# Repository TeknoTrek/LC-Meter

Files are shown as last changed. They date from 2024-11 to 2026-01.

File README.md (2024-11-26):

# DIY LC Meter Project

This project demonstrates how to build a DIY LC Meter capable of measuring inductance (L) and capacitance (C) values using an Arduino Nano, an LM311 comparator, and a 16x2 LCD display. The LC Meter is designed to be simple, affordable, and effective for electronics enthusiasts and DIY hobbyists. It is suitable for learning about measurement principles while also being a practical tool.

## Project Highlights:

### 1 - Circuit Schematic
A detailed circuit diagram explains the working principle and interconnection of components such as the LM311 comparator, relay, calibration buttons, and measurement probes. The schematic provides a foundation for assembling the hardware.

### 2 - PCB Design
A professionally designed single-layer PCB created with KiCad ensures clean routing and minimizes interference. It includes detailed silkscreen labels for easy assembly and debugging.

### 3 - 3D Model
A realistic 3D representation of the completed PCB with components mounted, offering a clear view of the final product and component placement.

### 4 - Firmware
The Arduino Nano is programmed with custom firmware to calculate inductance and capacitance values. Measurements are displayed on a 16x2 LCD in real time.

### 5 - Calibration and Functionality
The project includes functionality for calibration, zeroing, and easy measurement. Buttons on the PCB allow users to fine-tune settings for accurate results.

---

### Features:
- Precise Measurements: Measure a wide range of inductance and capacitance values.
- User-Friendly Interface: Includes a 16x2 LCD display for real-time measurement results and intuitive feedback.
- Adjustable Calibration: Easily calibrate the device for accurate readings using the on-board calibration buttons.
- Compact and Portable: The design is compact, making it easy to use in different workspaces or carry for fieldwork.

### Instructions:
### Prepare the PCB:
Download the provided Gerber files and manufacture the PCB, or use the KiCad design to etch your own board.

### Assemble Components:
Place and solder all components as per the silkscreen labels on the PCB.

### Upload Firmware:
Use the Arduino IDE to upload the provided sketch to your Arduino Nano. Ensure all libraries are correctly installed.

### Power and Calibration:
Connect the LC Meter to a 5V power source via USB or the provided input terminals. Calibrate the device using the calibration and zero buttons for precise results.

### Start Measuring:
Connect your inductors or capacitors to the respective terminals (Lx or Cx) and observe the measurement results on the LCD.

## Watch the Build Process

You can watch the full build process of this DIY LC Meter on my YouTube channel [**Teknotrek**](https://www.youtube.com/@TeknoTrek). Click the link below to see how the circuit is assembled, soldered, and tested:

[Watch on YouTube](https://youtu.be/YbbpxDlLRkQ)

## Files Included:
- Circuit schematic
- PCB design files (KiCad)
- 3D PCB model
- Arduino firmware
- Documentation with detailed assembly and usage instructions

## Circuit Schematic

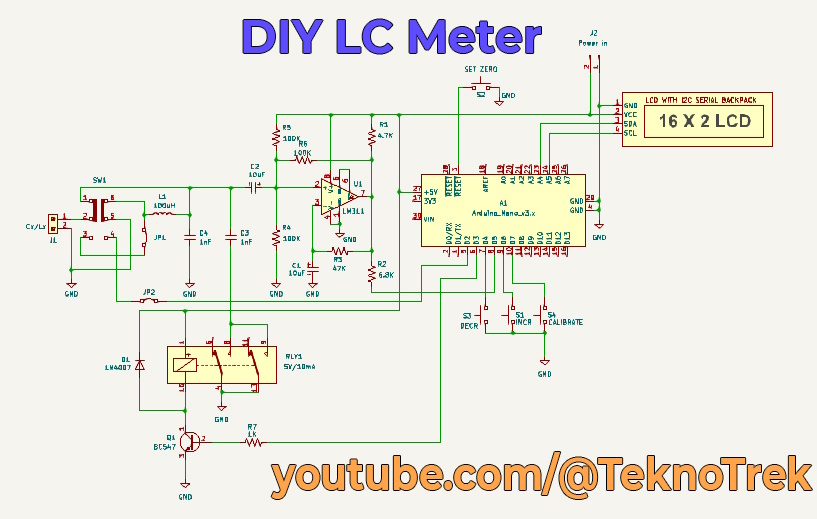
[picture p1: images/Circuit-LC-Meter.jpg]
DIY LC Meter Schematic


## PCB Layout

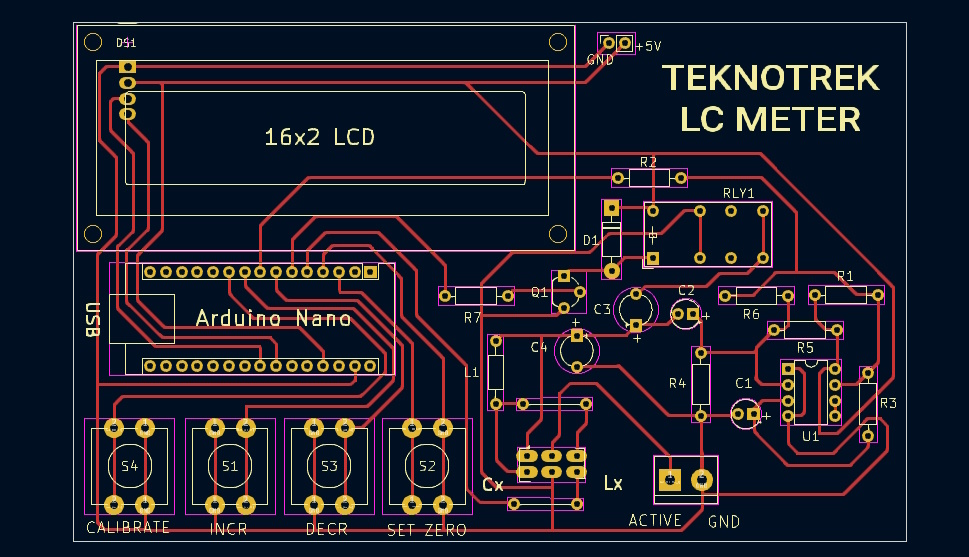
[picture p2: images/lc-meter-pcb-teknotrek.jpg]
PCB Layout


## 3D Model

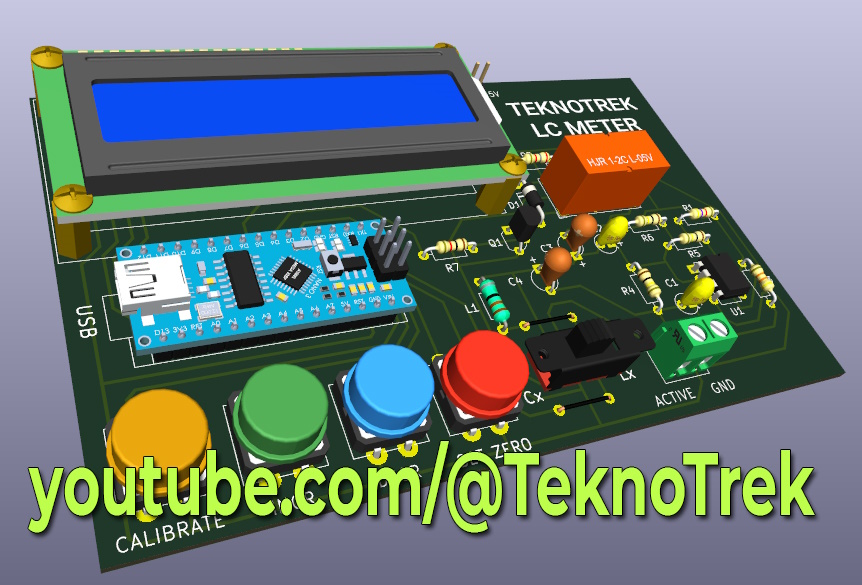
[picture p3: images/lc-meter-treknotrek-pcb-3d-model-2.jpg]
3D Model


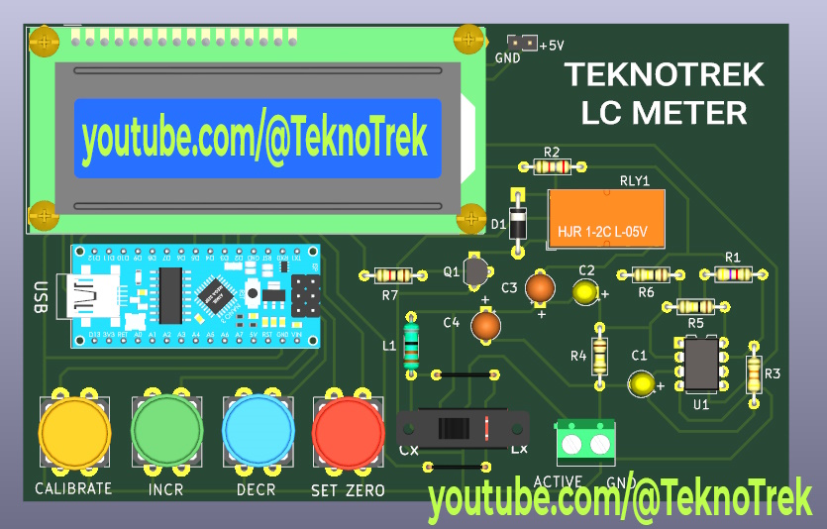
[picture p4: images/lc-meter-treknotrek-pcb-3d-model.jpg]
3D Model


## GitHub Repository:
All project files, including schematics, PCB designs, 3D models, and source code, are available on GitHub.

Check out the project here: [**Teknotrek**](https://www.youtube.com/@TeknoTrek)

This project is perfect for anyone interested in electronics, DIY tools, or Arduino projects. Whether you are a beginner or an experienced maker,this LC Meter provides a hands-on learning experience and a functional tool for your electronics toolkit!

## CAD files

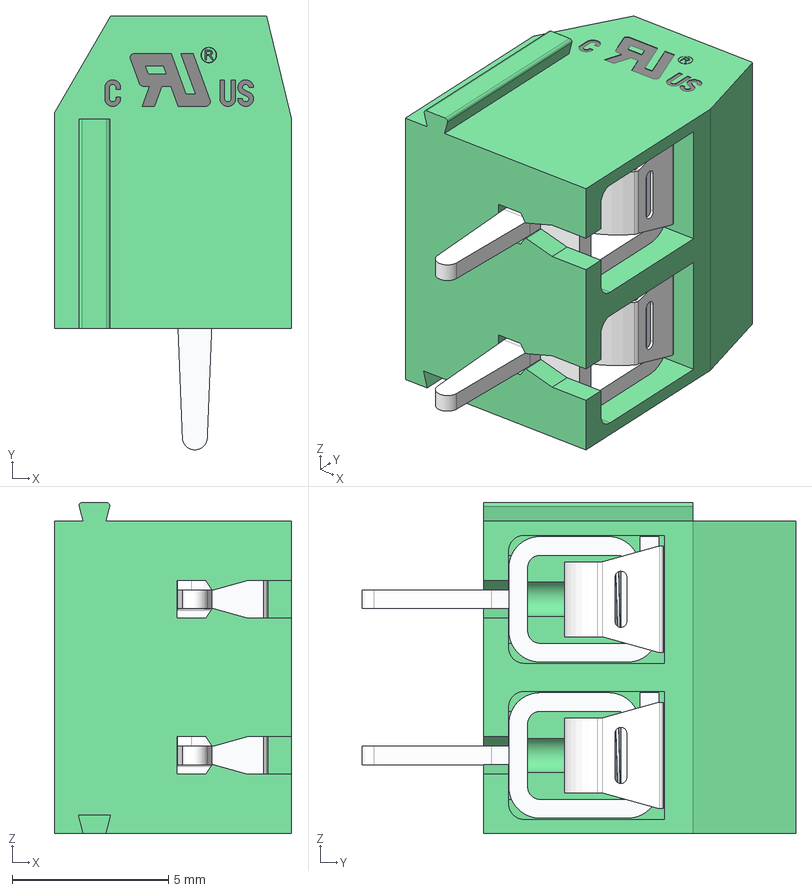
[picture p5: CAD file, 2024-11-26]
materiel/2 PIN DG306-5 GREEN - PITCH 5 mm.stp
7.60 x 13.9 x 10.6 mm

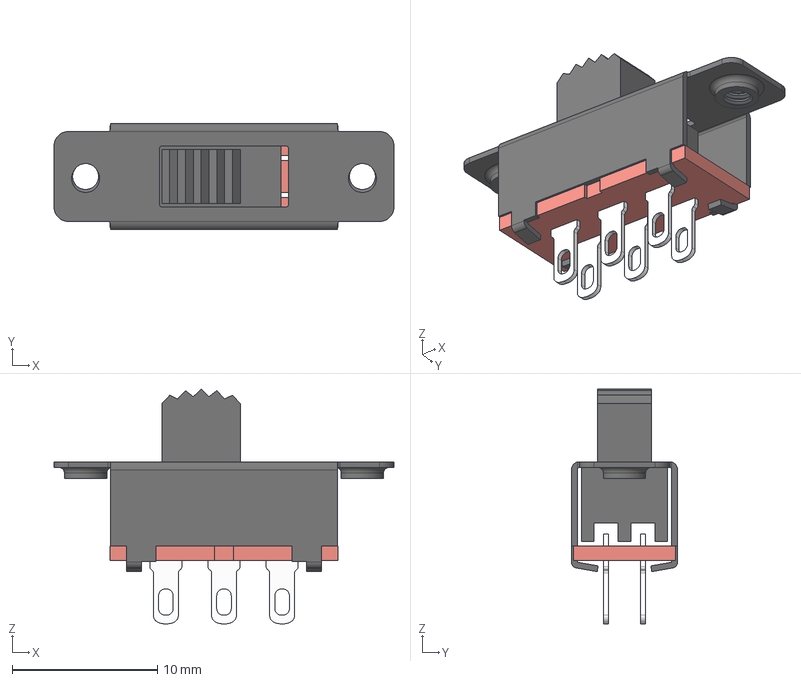
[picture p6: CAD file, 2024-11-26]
materiel/Uxcell 5mm Vertical Slide Switch DPDT 6 Terminals.step
23.4 x 7.30 x 16.2 mm

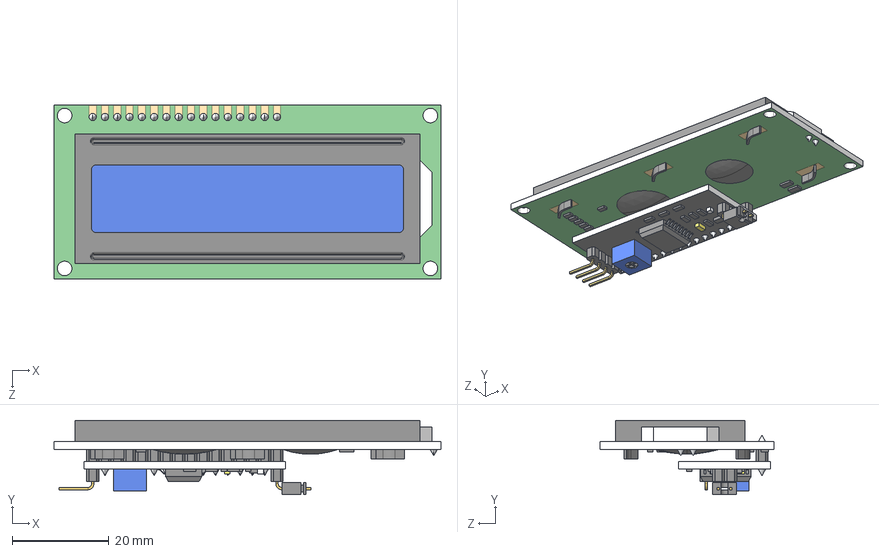
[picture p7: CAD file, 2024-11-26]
materiel/LCD_I2C_1602.STEP
80.0 x 15.4 x 36.0 mm

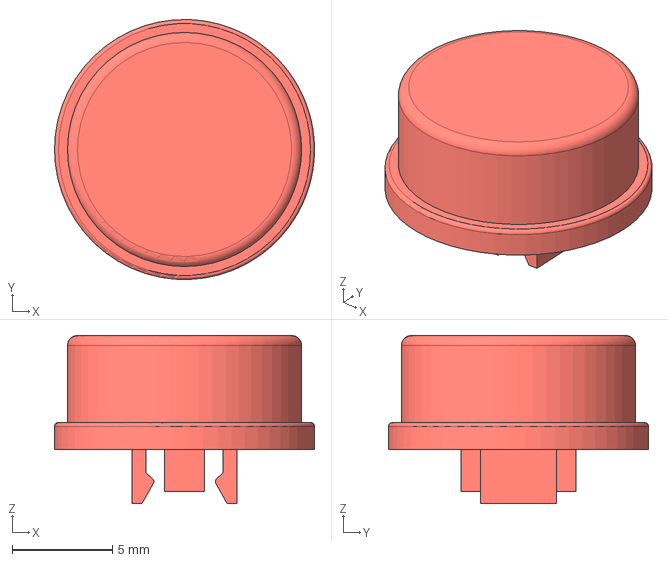
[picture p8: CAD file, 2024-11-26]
materiel/KLS7_TS1204_12x12-Cap_Red v1.step
13.0 x 13.0 x 8.40 mm

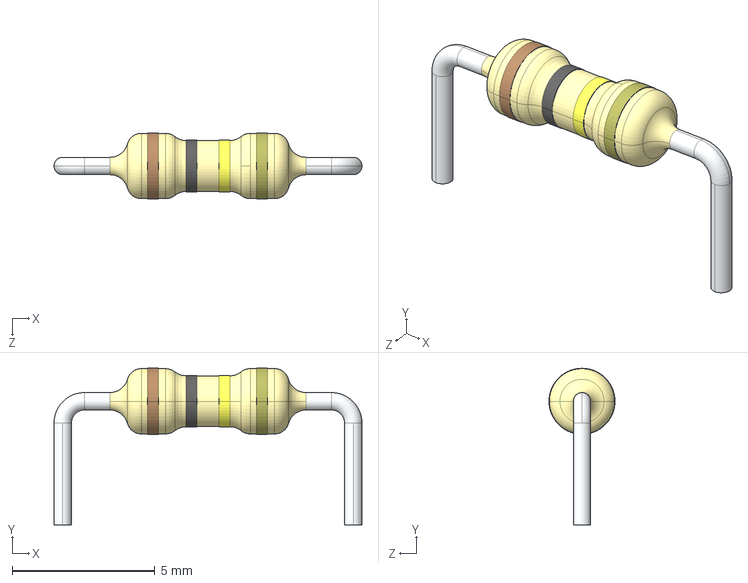
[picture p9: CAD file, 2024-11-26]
materiel/100kR 0.4.STEP
10.8 x 5.47 x 2.31 mm

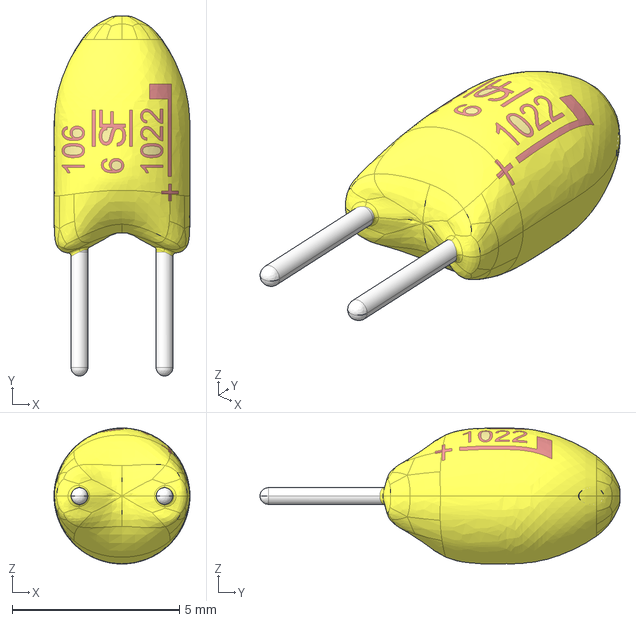
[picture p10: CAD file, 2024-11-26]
materiel/Cap Tan TH –Leads L3,5mm Radial Dipped T350.stp
4.06 x 10.7 x 4.06 mm

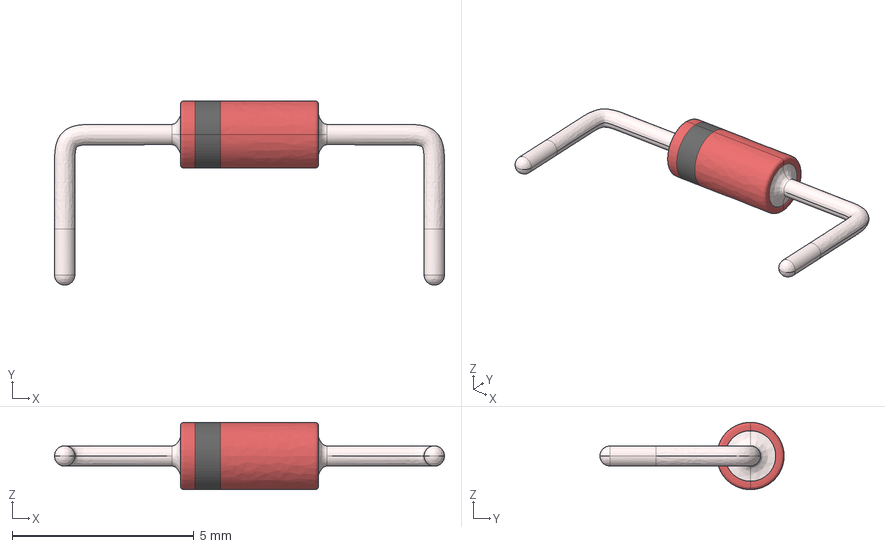
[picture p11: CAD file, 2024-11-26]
materiel/DO-35 Diode Horizontal.stp
10.7 x 5.07 x 1.85 mm

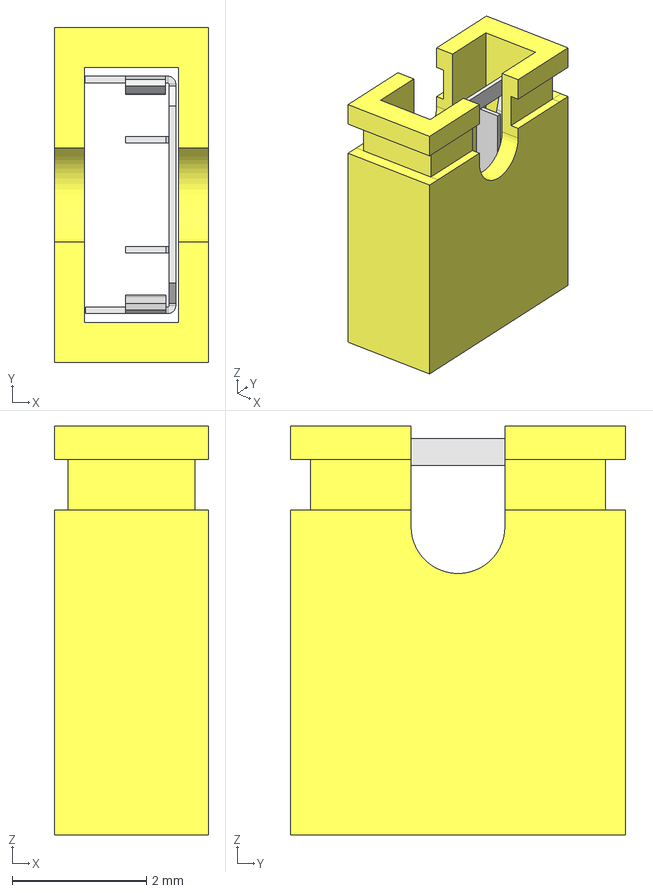
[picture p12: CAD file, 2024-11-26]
materiel/Jumper.step
2.30 x 5.00 x 6.10 mm
Frame
Jump

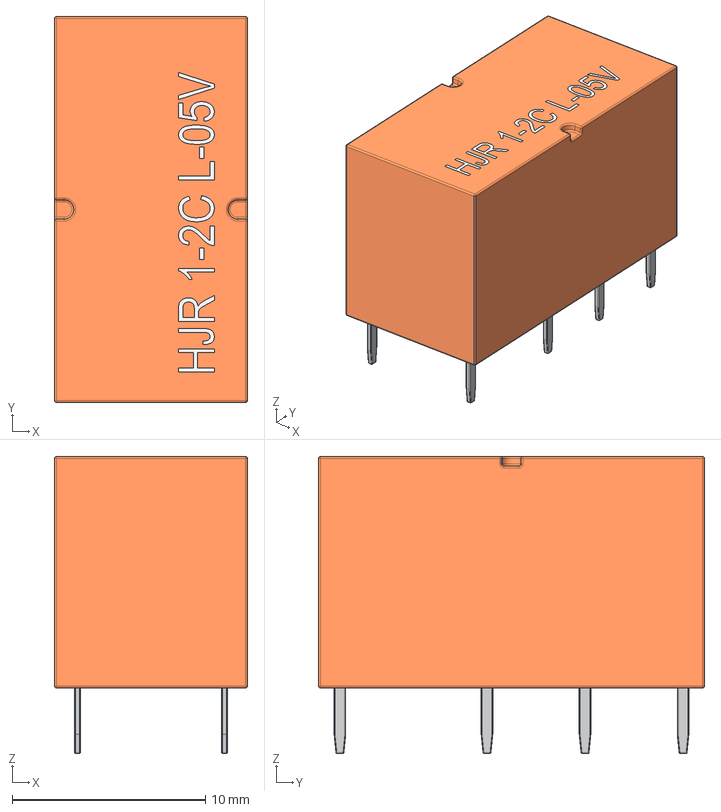
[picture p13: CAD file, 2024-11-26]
materiel/HJR_Series.step
10.0 x 20.0 x 15.5 mm
ShapeString

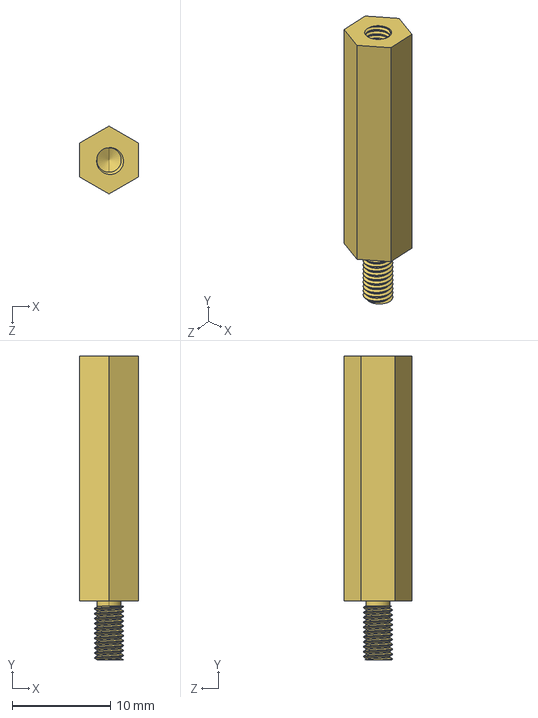
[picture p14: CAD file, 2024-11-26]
materiel/M3 x 6mm A-F x 25mm Hexagon Male-Female Threaded Pillar.STEP
6.00 x 31.0 x 6.93 mm

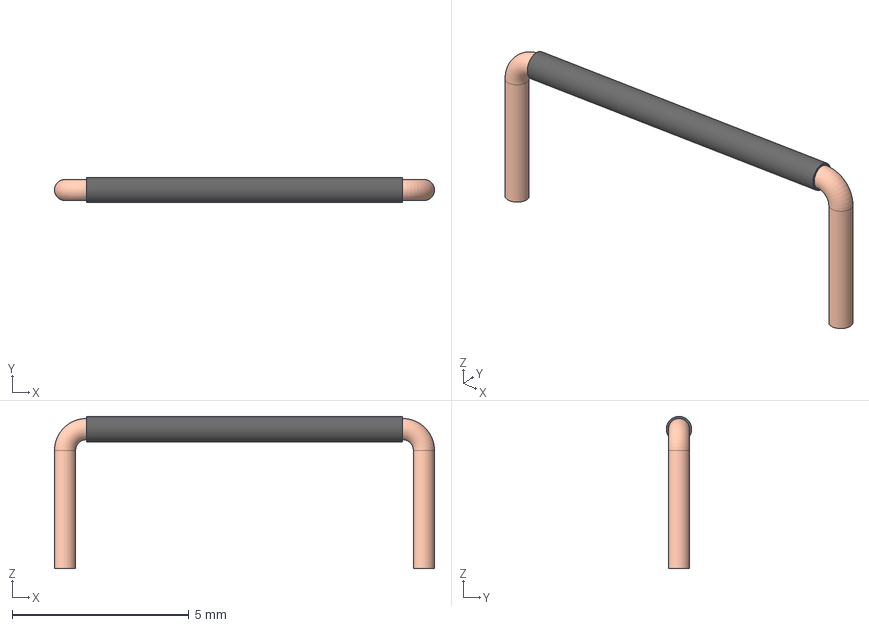
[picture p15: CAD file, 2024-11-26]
materiel/Wirebridge_10.16xD0.6mm.step
10.8 x 0.719 x 4.31 mm
Wire017
Isolation017

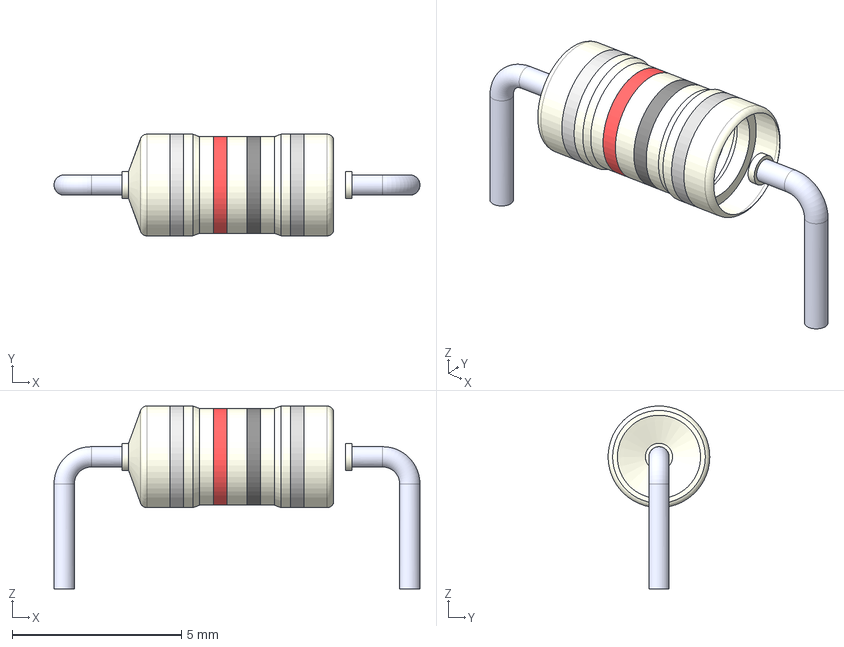
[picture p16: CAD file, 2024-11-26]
materiel/INDAD1020W60L680D300 v1.step
10.8 x 3.00 x 5.40 mm

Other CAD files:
materiel/4k7R 0.4.STEP
materiel/KLS7_TS1204_12x12-Cap_Gray v1.step
materiel/6k8R 0.4.STEP
materiel/47kR 0.4.STEP
materiel/KLS7_TS1204_12x12-Cap_Yellow v1.step
materiel/Cap Tan TH –Leads L4,0mm Radial Dipped T350.stp
materiel/1602 LCD.stp
materiel/1k 0.4.STEP
materiel/Cap Tan TH –Leads L12mm Radial Dipped T350.stp
materiel/KLS7_TS1204_12x12-Cap_Blue v1.step
materiel/KLS7_TS1204_12x12-Cap_Green v1.step
materiel/KLS7_TS1204_12x12.step
materiel/M4x10 PAN POZI HEAD SERRATED SCREW BRASS.STEP
materiel/OMRON B3F 12mm TACT SWITCH.STEP
materiel/inductor axial 10uH.STEP

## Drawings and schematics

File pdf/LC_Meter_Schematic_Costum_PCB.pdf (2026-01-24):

# LC Meter Schematic

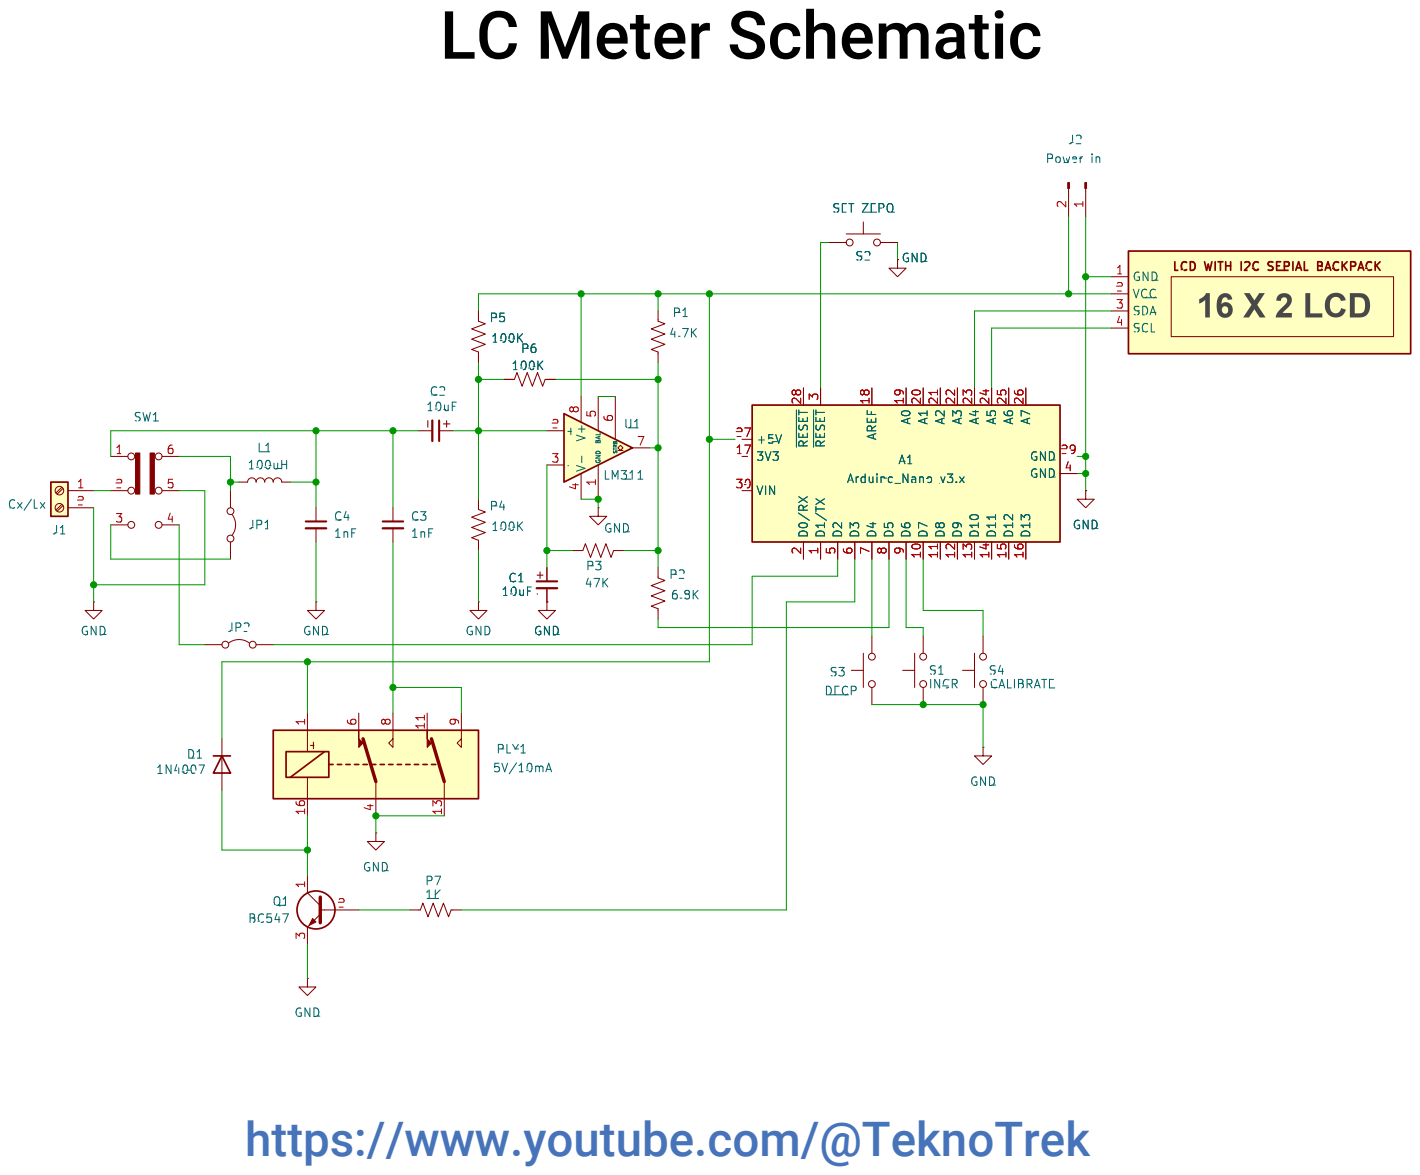
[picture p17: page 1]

LCD WITH I2C SERIAL BACKPACK GND 1
VCC 2
16 X 2 LCD

https://www.youtube.com/@TeknoTrek

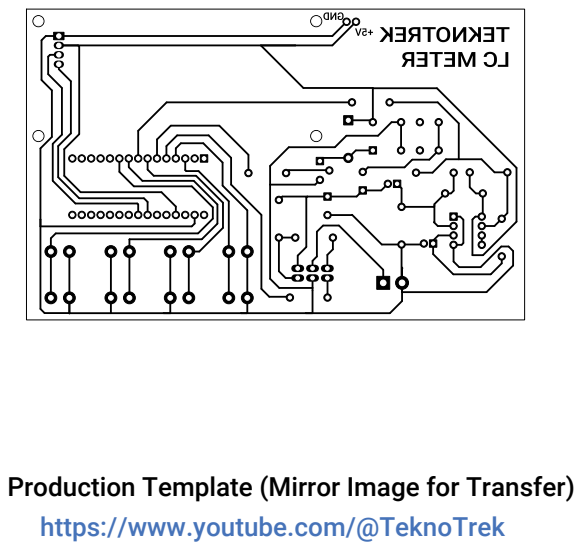
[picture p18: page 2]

Production Template (Mirror Image for Transfer)
https://www.youtube.com/@TeknoTrek

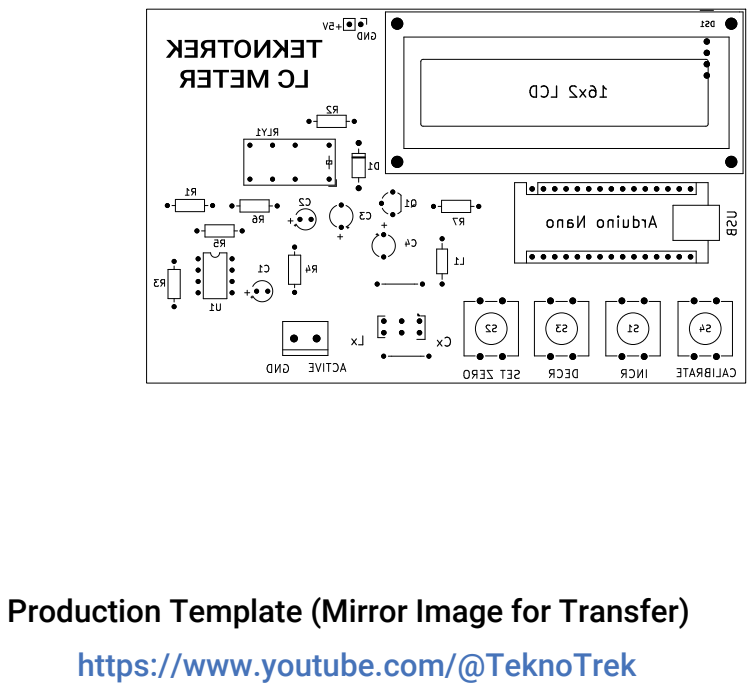
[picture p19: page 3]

Production Template (Mirror Image for Transfer) (https://www.youtube.com/@TeknoTrek)
https://www.youtube.com/@TeknoTrek

7

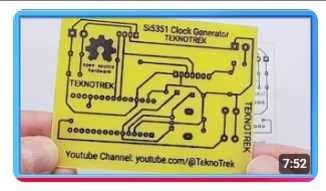
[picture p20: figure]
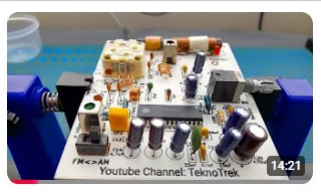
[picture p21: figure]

https://www.youtube.com/@TeknoTrek

🚀 Our Other Popular Electronics Projects
If you liked this radio, you’ll love these other projects on our channel! To access all our content, don't forget to subscribe!

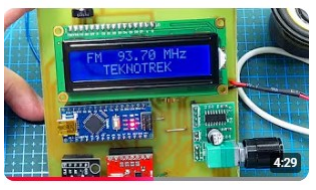
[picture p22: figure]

Home PCB Production: Easy and Fast Method! ️ | Si5351 Clock Generator (https://youtu.be/85aNuBdY58k) | How to Build a DIY FM Radio: Step-by-Step Guide with Arduino and Si4703 FM Module (https://youtu.be/up5PCYIprFo)
Watch Now (https://youtu.be/85aNuBdY58k) | Watch Now (https://youtu.be/up5PCYIprFo)

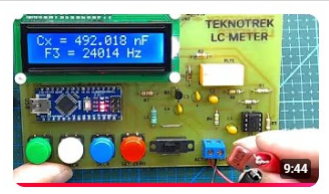
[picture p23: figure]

How to make AM / FM radio receiver at home | Powerful FM/AM Radio with CXA1019S! (https://youtu.be/TuUUNz7IGRk) | DIY Arduino-Based LC Meter - Measure Inductance and Capacitance (https://youtu.be/YbbpxDlLRkQ)
Watch Now (https://youtu.be/TuUUNz7IGRk) | Watch Now (https://youtu.be/YbbpxDlLRkQ)

To access all other videos on our channel:
Don't forget to subscribe to our channel! (https://www.youtube.com/@TeknoTrek) https://www.youtube.com/@TeknoTrek/videos

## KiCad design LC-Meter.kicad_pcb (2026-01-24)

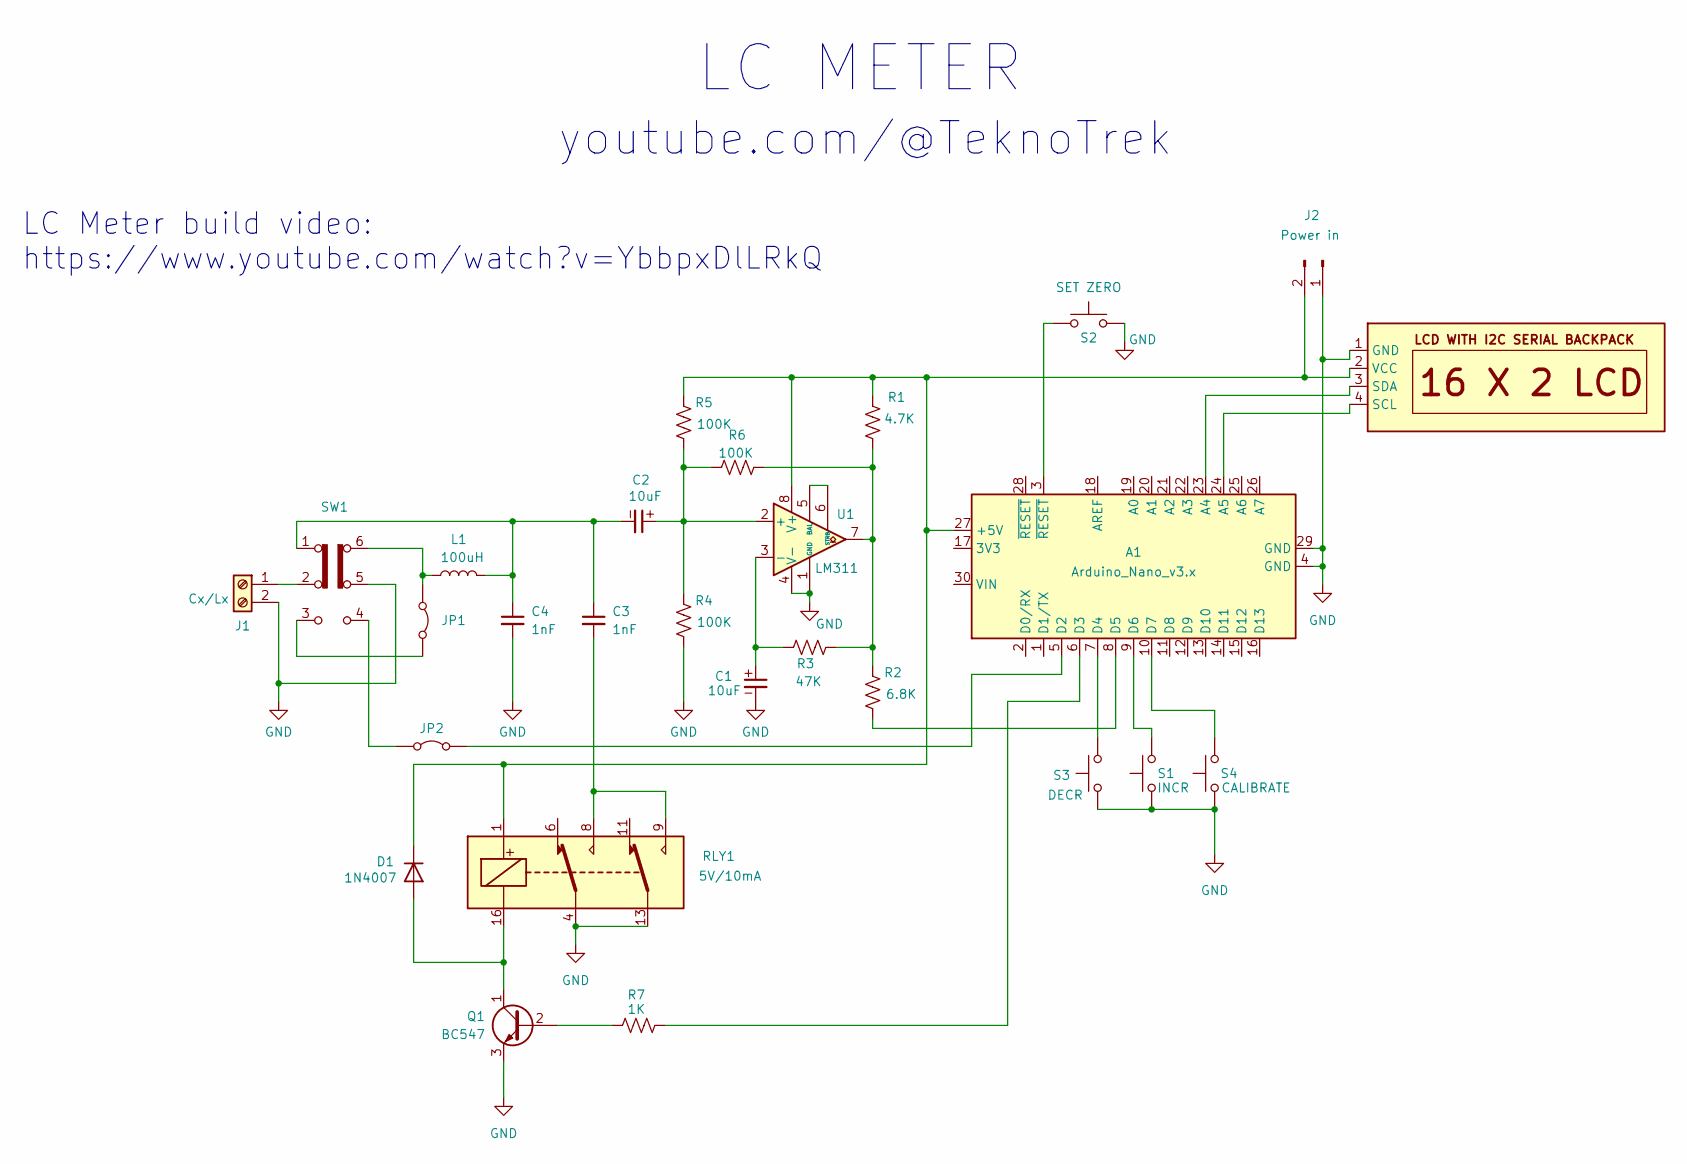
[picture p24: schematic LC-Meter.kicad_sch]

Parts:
A1: Arduino_Nano_v3.x; Arduino_Nano
C1, C2: 10uF; CP_Radial_Tantal_D4.5mm_P2.50mm
C3, C4: 1nF; CP_Radial_Tantal_D5.0mm_P5.00mm
D1: 1N4007; D_DO-41_SOD81_P10.16mm_Horizontal
DS1: WC1602A-I2C
J1: Cx/Lx; TerminalBlock_bornier-2_P5.08mm
J2: Power in; PinSocket_1x02_P2.54mm_Vertical
JP1, JP2: Jumper_2; R_Axial_DIN0207_L6.3mm_D2.5mm_P10.16mm_Horizontal
L1: 100uH; L_Axial_L5.3mm_D2.2mm_P10.16mm_Horizontal_Vishay_IM-1
Q1: BC547; TO-92_Wide
R1: 4.7K; R_Axial_DIN0207_L6.3mm_D2.5mm_P10.16mm_Horizontal
R2: 6.8K; R_Axial_DIN0207_L6.3mm_D2.5mm_P10.16mm_Horizontal
R3: 47K; R_Axial_DIN0207_L6.3mm_D2.5mm_P10.16mm_Horizontal
R4, R5, R6: 100K; R_Axial_DIN0207_L6.3mm_D2.5mm_P10.16mm_Horizontal
R7: 1K; R_Axial_DIN0207_L6.3mm_D2.5mm_P10.16mm_Horizontal
RLY1: 5V/10mA; TIANBO-HJR1-2CL-05V-footer
S1: INCR; SW_PUSH-12mm
S2: SET ZERO; SW_PUSH-12mm
S3: DECR; SW_PUSH-12mm
S4: CALIBRATE; SW_PUSH-12mm
SW1: SW_Slide_DPDT; SW_CK_
U1: LM311; DIP-8_W7.62mm

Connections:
GND: A1.4 (GND), A1.29 (GND), C1.2, C4.2, DS1.1 (GND), J1.2, J2.1, Q1.3 (E), R4.2, RLY1.4, RLY1.13, S1.1, S2.2, S3.1, S4.1, SW1.5 (B), U1.1 (GND), U1.4 (V-)
unnamed: A1.27 (+5V), D1.1 (K), DS1.2 (VCC), J2.2, R1.1, R5.1, RLY1.1, U1.8 (V+)
unnamed: A1.23 (A4), DS1.3 (SDA)
unnamed: A1.24 (A5), DS1.4 (SCL)
unnamed: A1.5 (D2), JP2.2 (B)
unnamed: A1.6 (D3), R7.2
unnamed: A1.7 (D4), S3.2
unnamed: A1.8 (D5), R2.2
unnamed: A1.9 (D6), S1.2
unnamed: A1.10 (D7), S4.2
unnamed: A1.3 (~RESET), S2.1
unnamed: C2.2, C3.1, C4.1, L1.2, SW1.1 (A)
unnamed: C3.2, RLY1.8, RLY1.9
unnamed: D1.2 (A), Q1.1 (C), RLY1.16
unnamed: J1.1, SW1.2 (B)
unnamed: JP1.1 (A), L1.1, SW1.6 (C)
unnamed: JP1.2 (B), SW1.3 (C)
unnamed: JP2.1 (A), SW1.4 (A)
unnamed: Q1.2 (B), R7.1
unnamed: R1.2, R2.1, R3.2, R6.2, U1.7
unnamed: C2.1, R4.1, R5.2, R6.1, U1.2 (+)
unnamed: C1.1, R3.1, U1.3 (-)
unnamed: U1.5 (BAL), U1.6 (STRB)

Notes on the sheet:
LC Meter build video: https://www.youtube.com/watch?v=YbbpxDlLRkQ
youtube.com/@TeknoTrek
LC METER

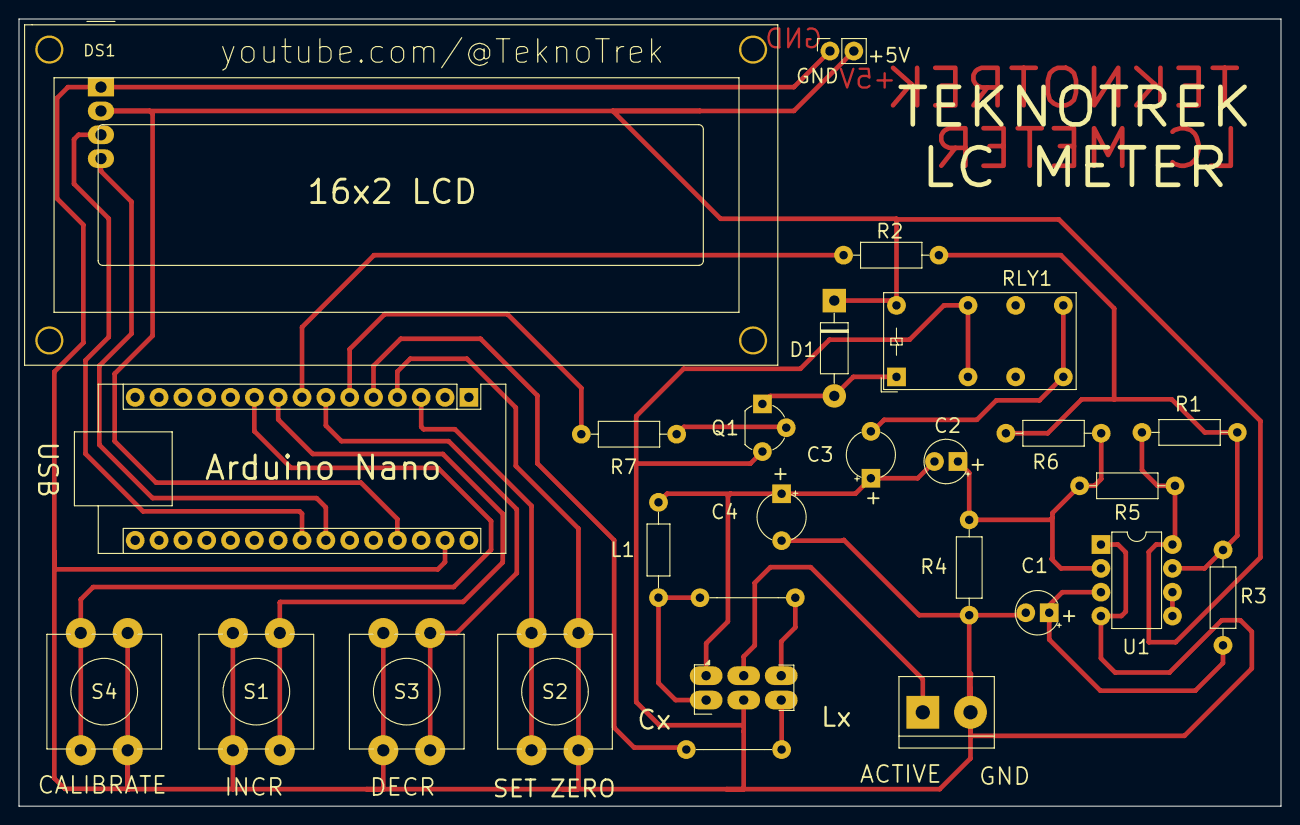
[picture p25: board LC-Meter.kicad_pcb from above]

Board: 2 copper layers, 134.5 x 83.9 mm, 27 parts (0 on the bottom side), 23 nets.
